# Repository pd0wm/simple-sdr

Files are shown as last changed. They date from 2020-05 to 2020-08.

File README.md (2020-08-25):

# simple-sdr PCB
Simple Software Defined Radio based on [Softrock Lite II](http://wb5rvz.org/softrock_lite_ii/index/projectId=8). The IF generation and sampling is handled by an STM32F042. This design is intended to build a low cost [NAVTEX](https://en.wikipedia.org/wiki/NAVTEX) receiver, but can be used for all kinds of purposes. The current design has an input bandpass filter ranging from 400 - 1600 KHz.

WARNING: So far I haven't been able to receive anything yet with this hardware. Please use at your own risk.

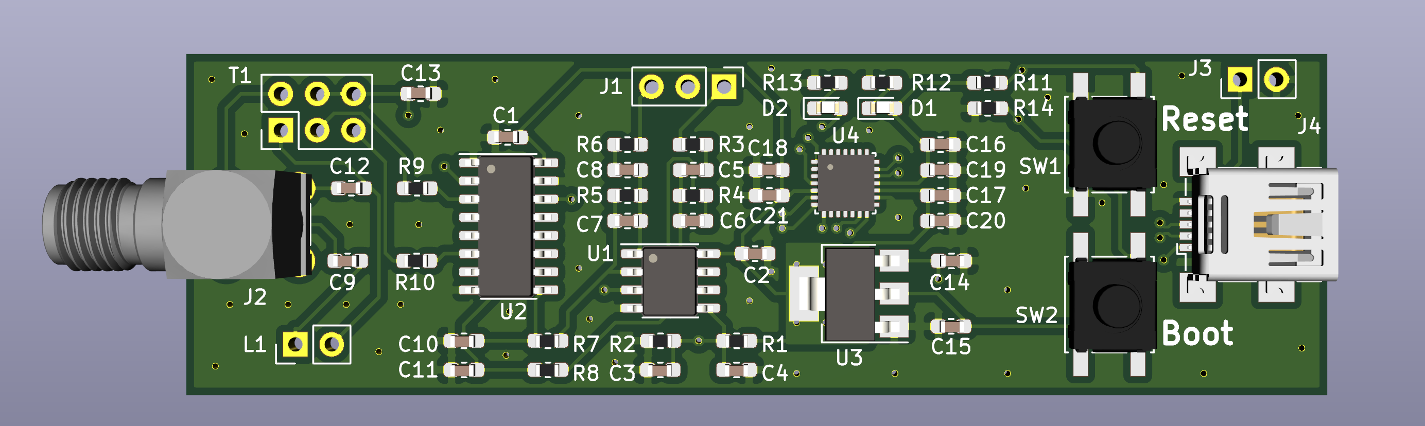
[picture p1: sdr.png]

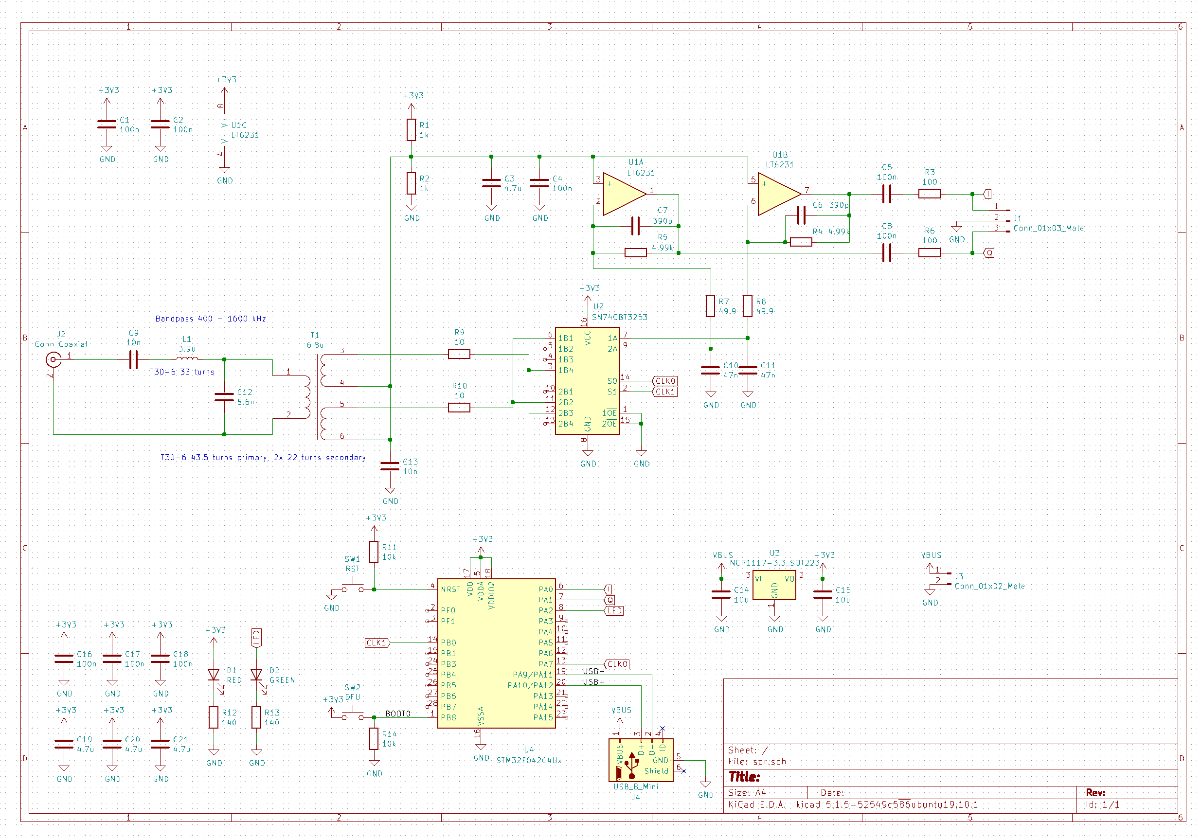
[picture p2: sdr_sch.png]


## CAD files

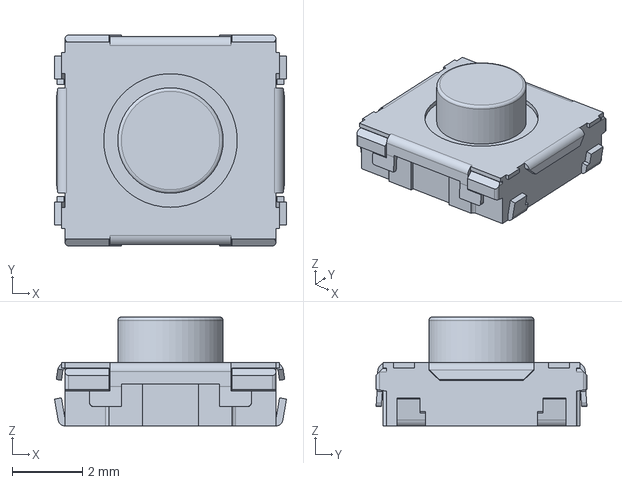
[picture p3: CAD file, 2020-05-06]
pcb/3d/Switch_Panasonic_EVQ-Q2B03W_eec.STEP
6.60 x 6.00 x 3.10 mm

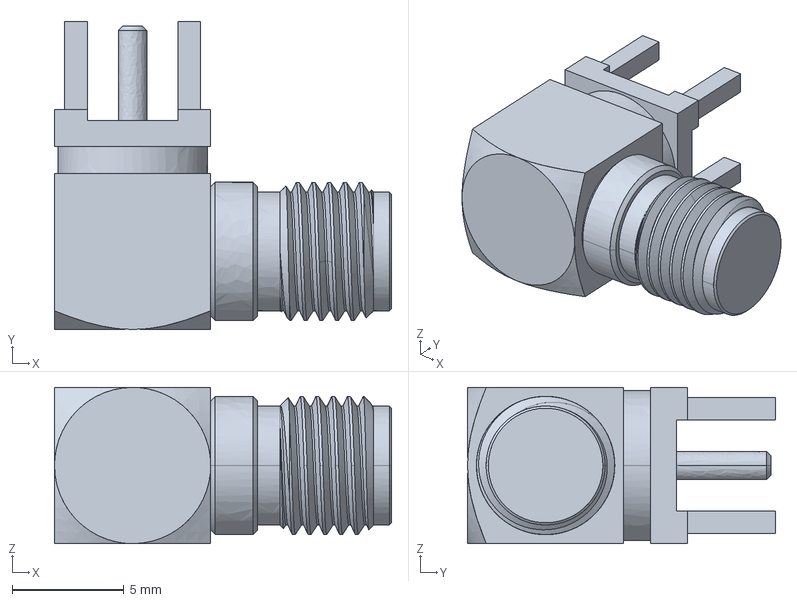
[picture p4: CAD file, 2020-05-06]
pcb/3d/132136_3d_model.igs
15.1 x 13.8 x 7.00 mm

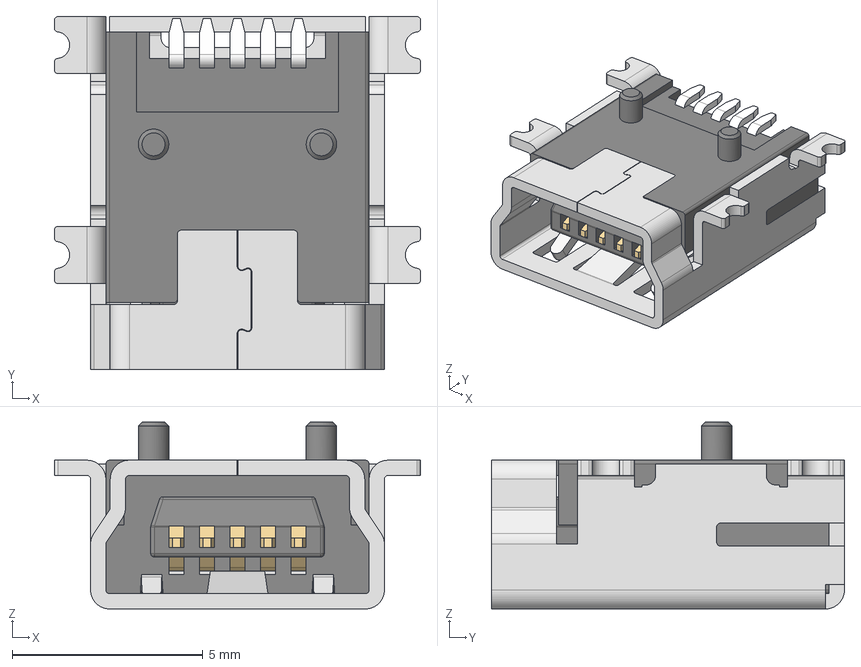
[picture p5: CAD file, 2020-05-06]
pcb/3d/65100516121_Download_STP_65100516121_rev1.stp
9.60 x 9.25 x 4.90 mm
Shielding
Insulator
Pin_1 x 5

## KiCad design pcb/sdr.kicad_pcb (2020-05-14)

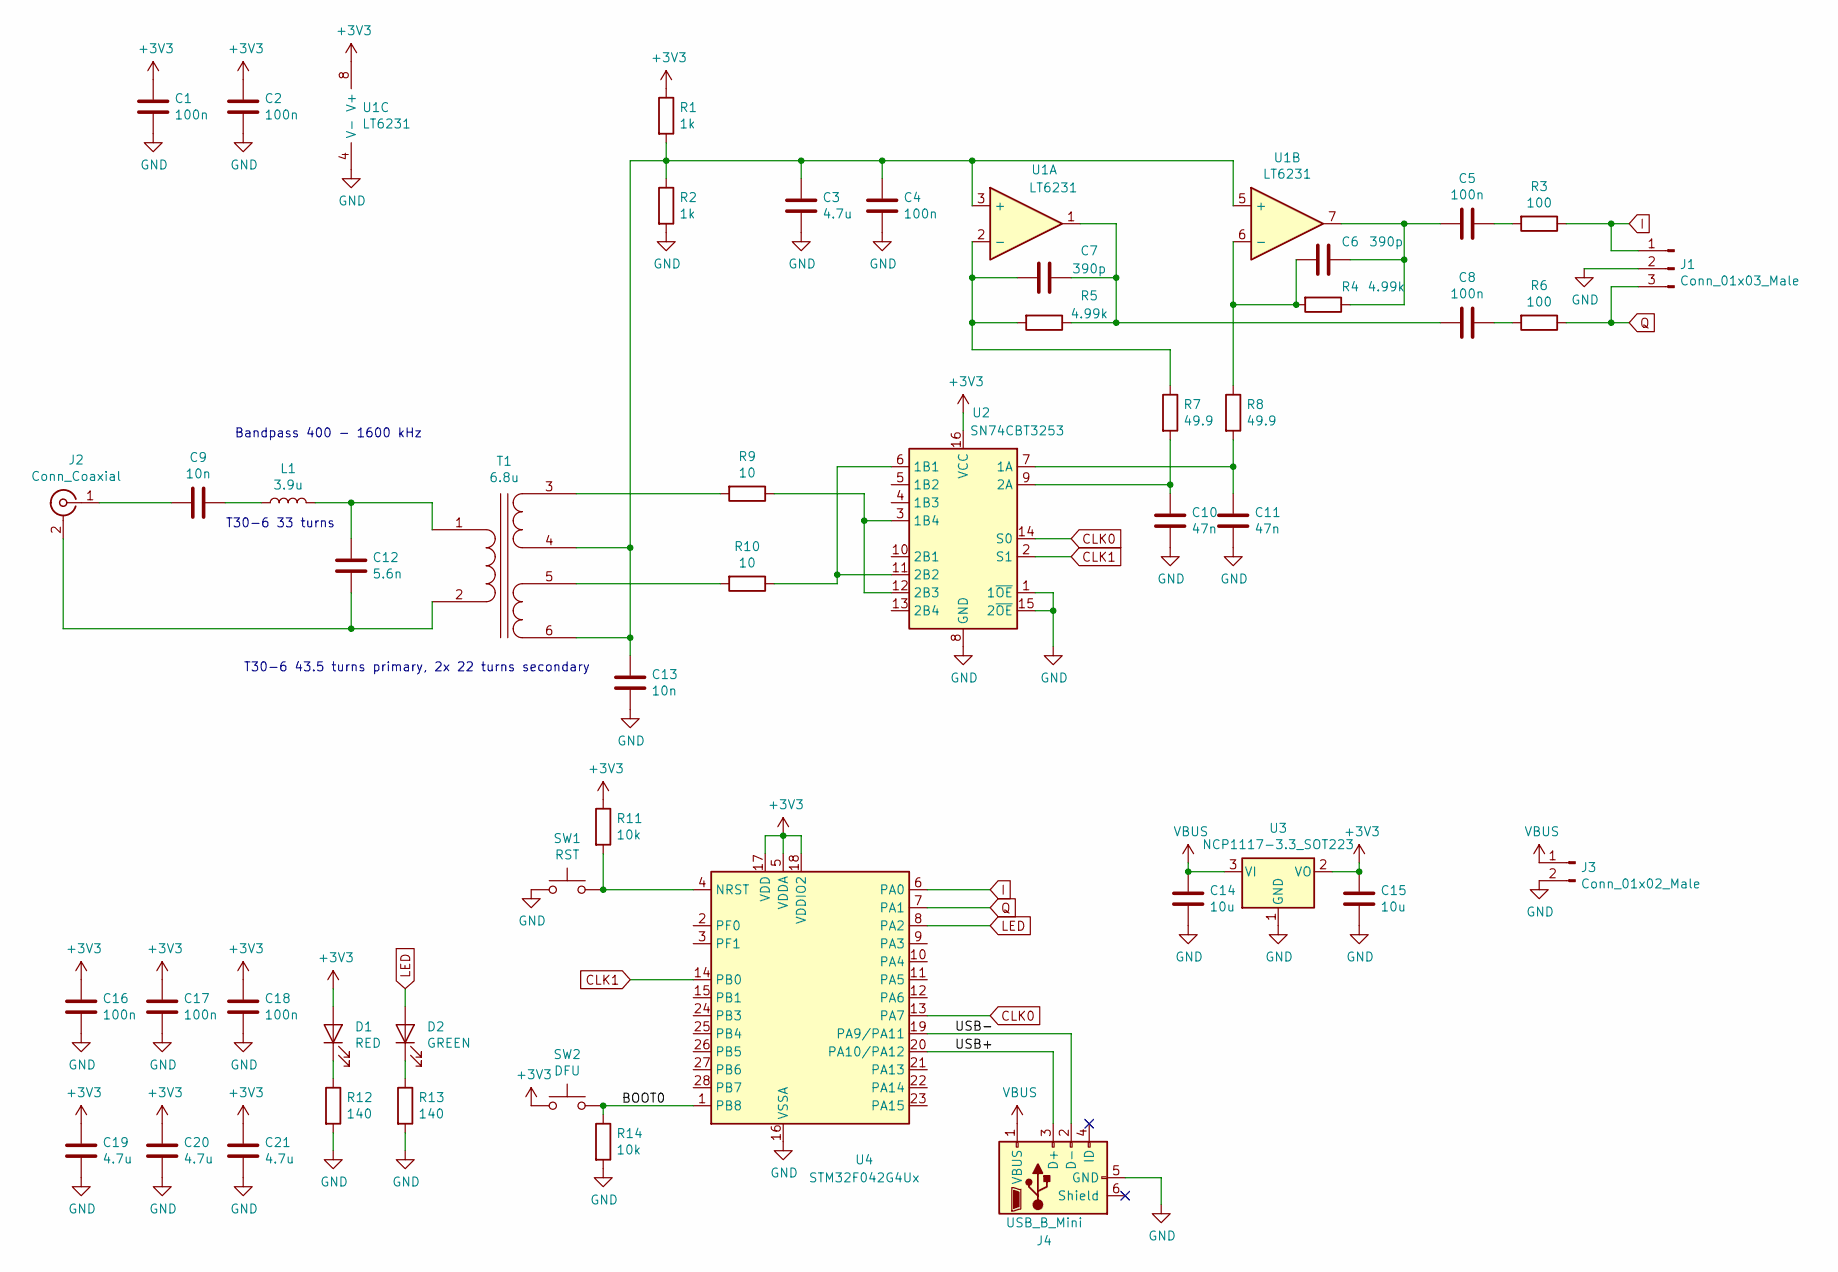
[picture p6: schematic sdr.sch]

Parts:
C1, C2, C4, C5, C8, C16, C17, C18: 100n; C_0603_1608Metric_Pad1.05x0.95mm_HandSolder; Digikey 399-1100-1-ND
C3, C19, C20, C21: 4.7u; C_0603_1608Metric_Pad1.05x0.95mm_HandSolder; Digikey 1276-1907-1-ND
C6, C7: 390p; C_0603_1608Metric_Pad1.05x0.95mm_HandSolder; Digikey 399-14983-1-ND
C9, C13: 10n; C_0603_1608Metric_Pad1.05x0.95mm_HandSolder; Digikey 399-7842-1-ND
C10, C11: 47n; C_0603_1608Metric_Pad1.05x0.95mm_HandSolder; Digikey 1276-1063-1-ND
C12: 5.6n; C_0603_1608Metric_Pad1.05x0.95mm_HandSolder; Digikey 1276-2091-1-ND
C14, C15: 10u; C_0603_1608Metric_Pad1.05x0.95mm_HandSolder; Digikey 490-13248-1-ND
D1: RED; LED_0603_1608Metric_Pad1.05x0.95mm_HandSolder; Digikey 732-4978-1-ND
D2: GREEN; LED_0603_1608Metric_Pad1.05x0.95mm_HandSolder; Digikey 732-4971-1-ND
J1: Conn_01x03_Male; PinHeader_1x03_P2.54mm_Vertical
J2: Conn_Coaxial; SMA_Amphenol_901-144_Vertical
J3: Conn_01x02_Male; PinHeader_1x02_P2.54mm_Vertical
J4: USB_B_Mini; USB_Mini-B_Wuerth_65100516121_Horizontal; Digikey 732-2109-1-ND
L1: 3.9u; PinHeader_1x02_P2.54mm_Vertical
R1, R2: 1k; R_0603_1608Metric_Pad1.05x0.95mm_HandSolder; Digikey 311-1.00KHRCT-ND
R3, R6: 100; R_0603_1608Metric_Pad1.05x0.95mm_HandSolder; Digikey 311-100HRCT-ND
R4, R5: 4.99k; R_0603_1608Metric_Pad1.05x0.95mm_HandSolder; Digikey 311-4.99KHRCT-ND
R7, R8: 49.9; R_0603_1608Metric_Pad1.05x0.95mm_HandSolder; Digikey 311-49.9HRCT-ND
R9, R10: 10; R_0603_1608Metric_Pad1.05x0.95mm_HandSolder; Digikey 311-10.0HRCT-ND
R11, R14: 10k; R_0603_1608Metric_Pad1.05x0.95mm_HandSolder; Digikey 311-10.0KHRCT-ND
R12, R13: 140; R_0603_1608Metric_Pad1.05x0.95mm_HandSolder; Digikey 311-140HRCT-ND
SW1: RST; SW_SPST_EVQQ2; Digikey P12932SCT-ND
SW2: DFU; SW_SPST_EVQQ2; Digikey P12932SCT-ND
T1: 6.8u; PinHeader_2x03_P2.54mm_Vertical
U1: LT6231; SOIC-8_3.9x4.9mm_P1.27mm; Digikey LT6231CS8#PBF-ND
U2: SN74CBT3253; SOIC-16_3.9x9.9mm_P1.27mm; Digikey 296-19206-1-ND
U3: NCP1117-3.3_SOT223; SOT-223-3_TabPin2; Digikey NCP1117LPST33T3GOSCT-ND
U4: STM32F042G4Ux; QFN-28_4x4mm_P0.5mm; Digikey 497-17830-ND

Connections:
+3V3: C1.1, C2.1, C15.1, C16.1, C17.1, C18.1, C19.1, C20.1, C21.1, D1.2 (A), R1.1, R11.1, SW2.1, U1.8 (V+), U2.16 (VCC), U3.2 (VO), U4.5 (VDDA), U4.17 (VDD), U4.18 (VDDIO2)
/BOOT0: R14.1, SW2.2, U4.1 (PB8)
/USB+: J4.3 (D+), U4.20 (PA10/PA12)
/USB-: J4.2 (D-), U4.19 (PA9/PA11)
CLK0: U2.14 (S0), U4.13 (PA7)
CLK1: U2.2 (S1), U4.14 (PB0)
GND: C1.2, C2.2, C3.2, C4.2, C10.2, C11.2, C13.2, C14.2, C15.2, C16.2, C17.2, C18.2, C19.2, C20.2, C21.2, J1.2, J3.2, J4.5 (GND), R2.2, R12.2, R13.2, R14.2, SW1.1, U1.4 (V-), U2.1 (1~OE), U2.8 (GND), U2.15 (2~OE), U3.1 (GND), U4.16 (VSSA)
I: J1.1, R3.1, U4.6 (PA0)
LED: D2.2 (A), U4.8 (PA2)
unnamed: C5.1, R3.2
unnamed: C5.2, C6.1, R4.1, U1.7
unnamed: C6.2, R4.2, R8.1, U1.6 (-)
unnamed: C7.1, C8.2, R5.1, U1.1
unnamed: C7.2, R5.2, R7.1, U1.2 (-)
unnamed: C8.1, R6.2
unnamed: C9.1, L1.1
unnamed: C9.2, J2.1 (In)
unnamed: C10.1, R7.2, U2.9 (2A)
unnamed: C11.1, R8.2, U2.7 (1A)
unnamed: C12.1, L1.2, T1.1 (AA)
unnamed: C12.2, J2.2 (Ext), T1.2 (AB)
unnamed: C3.1, C4.1, C13.1, R1.2, R2.1, T1.4 (SB), T1.6 (SD), U1.3 (+), U1.5 (+)
unnamed: D1.1 (K), R12.1
unnamed: D2.1 (K), R13.1
unnamed: R9.1, U2.3 (1B4), U2.12 (2B3)
unnamed: R9.2, T1.3 (SA)
unnamed: R10.1, U2.6 (1B1), U2.11 (2B2)
unnamed: R10.2, T1.5 (SC)
unnamed: R11.2, SW1.2, U4.4 (NRST)
Q: J1.3, R6.1, U4.7 (PA1)
VBUS: C14.1, J3.1, J4.1 (VBUS), U3.3 (VI)

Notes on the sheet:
T30-6 33 turns
T30-6 43.5 turns primary, 2x 22 turns secondary
Bandpass 400 - 1600 kHz

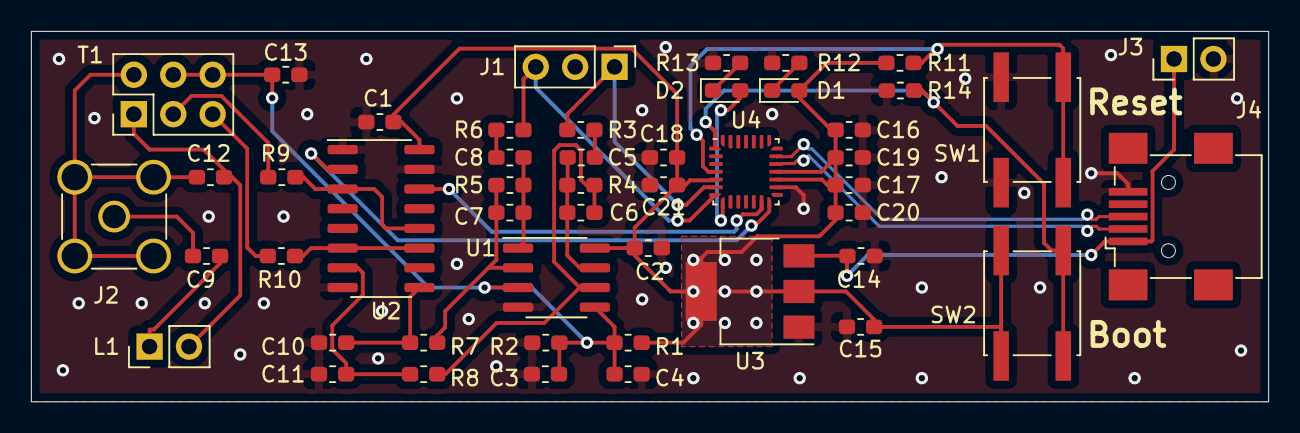
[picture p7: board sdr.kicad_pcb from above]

Board: 2 copper layers, 79.8 x 23.9 mm, 49 parts (0 on the bottom side), 31 nets.

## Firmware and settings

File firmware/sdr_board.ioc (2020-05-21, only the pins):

Mcu.UserName=STM32F042G6Ux
PA1.Signal=ADC_IN1
PA2.Signal=S_TIM2_CH3
PA0.Signal=ADC_IN0
PB0.Signal=TIM1_CH2N
PA7.Signal=TIM1_CH1N

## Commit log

2020-05-06 add schematic picture
2020-05-07 add gerbers as ordered
    [sdr-B_Cu.gbr, sdr-B_Mask.gbr, sdr-B_Paste.gbr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]
2020-05-14 connect missing wire
    [sdr.kicad_pcb]
2020-05-14 move into folder
    [132136_3d_model.igs, 65100516121_Download_STP_65100516121_rev1.stp, Switch_Panasonic_EVQ-Q2B03W_eec.STEP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]
2020-05-21 led is blinking on timer
